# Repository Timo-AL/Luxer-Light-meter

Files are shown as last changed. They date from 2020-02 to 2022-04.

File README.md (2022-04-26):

# Lux-Light-meter
A light meter designed for taking photo（用于摄影的测光表）

## 如何制作

LMG2MB_gerber文件夹里面的zip去找板厂下单，建议嘉立创哑光黑阻焊，减少反光影响

LMG2MV_BOM.xlsx 对照采购原件，尤其注意type-c封装

R11限流电阻根据情况使用，我用的VA 3.3V的1602，选的0欧

安装luattool v2，下载库中的LuatOS-SoC_V0007_AIR103.soc和main.lua

调节旋钮，使液晶屏字符清晰，最好用陶瓷螺丝刀，小心短路

## 如何使用
avatar

B1 电源开关

B2 模式选择，长按在A（光圈优先），S（快门优先），L（低感光度光圈优先），I（感光度设置）模式之间切换

R1 曝光补偿旋钮

R2 参数旋钮

D1 电池电压，低于3.4时需要充电

D2 曝光误差，误差大于0.3EV时显示+，小于-0.3EV显示减号，大于±1EV显示E，小于±0.3EV显示=

D3 ISO值

D4 工作模式

D4 快门速度，速度低于1S会以“秒数"”格式显示

D6 光圈

D7 曝光补偿，设置感光度时该位置显示低感值

## 下载固件

avatar

按如图所示线序与CH340串口模块连接，TX和RX需要交叉，不连接VCC

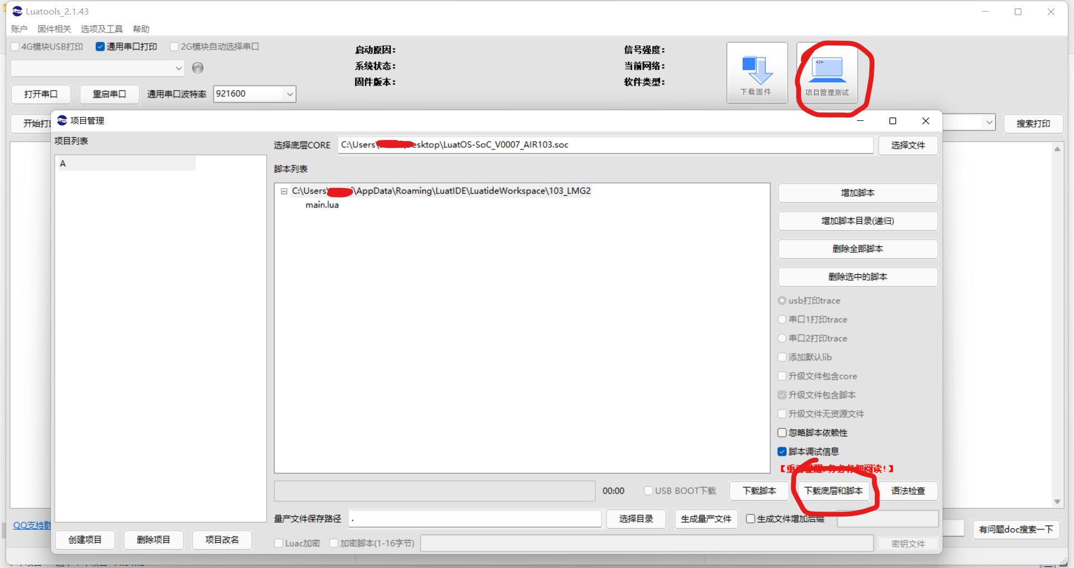
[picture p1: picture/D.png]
avatar


按如图所示方法下载固件，开始下载后打开打开测光表电源

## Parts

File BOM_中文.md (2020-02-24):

名称|丝印|数量|备注
-|-|-|-
外壳|无|1|3D打印仓库中的STEP文件
PCB|无|1|制造文件可以在仓库中下载
旋转编码器|JP5|1|Nidec SD-1110 外壳10*10 手柄直径3.9
DC插座|DC1|1|面板安装，开孔直径8
船型开关|JP3|1|面板安装，开孔6.8*19.2
按键开关|JP5|1|面板安装，开孔直径7.5，无自锁
FPC连接器|FCP1~FCP2|2|16P间隔1.0mm
FPC线|N.A.|1|适合连接器即可
Arduino Nano|MODUL1|1|无
电源管理模块|MODUL2|1|MH-CD42
HPDL1414|D1~D4|1|no remark
传感器|JP2|1|B-LUX-V30B

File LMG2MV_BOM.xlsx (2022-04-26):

Date: | 2022-04-26 18:18
Tool: | Eeschema (6.99.0-1665-g4ee6cfe5b6)
Generator: | C:\Program Files\KiCad\6.99\bin\scripting\plugins/bom_csv_grouped_by_value_with_fp.py
Component Count: | 56
Ref | Qnty | Value | Footprint | Description | Vendor
C1, C2, C3, C4, C6, C7, C8, C9, C10, C16, C25, | 11 | 100nf | Capacitor_SMD:C_0603_1608Metric
C12, C14, C22, | 3 | 10uf | Capacitor_SMD:C_0603_1608Metric
C13, | 1 | 100nF | Capacitor_SMD:C_0603_1608Metric
C15, C17, | 2 | 10uf | Capacitor_SMD:CP_Elec_4x4.5
C18, C19, C20, C21, | 4 | 20pf | Capacitor_SMD:C_0603_1608Metric
C23, C24, | 2 | 100uf | Capacitor_SMD:CP_Elec_6.3x5.4
D1, D2, | 2 | LED | LED_SMD:LED_0805_2012Metric
J1, | 1 | USB_C_Receptacle_USB2.0 | Connector_USB:USB_C_Receptacle_XKB_U262-16XN-4BVC11
J3, | 1 | Conn_01x04 | Connector_PinHeader_2.54mm:PinHeader_1x04_P2.54mm_Vertical
R1, R2, | 2 | 5.1K | Resistor_SMD:R_0603_1608Metric
R3, | 1 | 1.2K | Resistor_SMD:R_0603_1608Metric
R4, R5, | 2 | 200 | Resistor_SMD:R_0603_1608Metric
R6, R7, | 2 | 10k | Resistor_SMD:R_0603_1608Metric
R8, | 1 | 1k | Resistor_SMD:R_0603_1608Metric
R9, R10, | 1 | 4.22k | Resistor_SMD:R_0603_1608Metric | 精度千分之一
R11, | 1 | 510 | Resistor_SMD:R_0603_1608Metric
RV1, | 1 | 10k | Potentiometer_THT:Potentiometer_Vishay_T73XW_Horizontal | 调整对比度的时候手一定要稳，惨痛教训
SW1, SW2, | 2 | XKB7070-Z | FP:SW-TH_6P-L7.0-W7.0-P2.00
U1, | 1 | TP4056 | Package_SO:SOIC-8-1EP_3.9x4.9mm_P1.27mm_EP2.29x3mm
U2, | 1 | ME6211C33 | Package_TO_SOT_SMD:SOT-23-5
U3, | 1 | BH1620FVC-TR | FP:WSOF-5_L1.6-W1.2-P0.50-TL
U4, | 1 | BH1620FVC-TR | FP:PinHeader_1x05_P1.27mm_Vertical_SMD_Pin1Right
U5, | 1 | AIR103_CORE_QFN | FP:QFN-56_L6.0-W6.0-P0.35-BL-EP4.7
U6, U7, | 2 | BCD8421_3-3 | FP:BCD8421_3-3
U8, | 1 | RC1602A | Display:WC1602A | 推荐使用VA屏，对比度高
U9, | 1 | LMC6482 | Package_SO:SOIC-8_3.9x4.9mm_P1.27mm
Y1, | 1 | 40MHz | Crystal:Crystal_SMD_TXC_7A-2Pin_5x3.2mm
J2 | 1 | 803040电池
 | 1 | 余弦修正器 |  | 就是光照传感器的盖子，外径25mm左右

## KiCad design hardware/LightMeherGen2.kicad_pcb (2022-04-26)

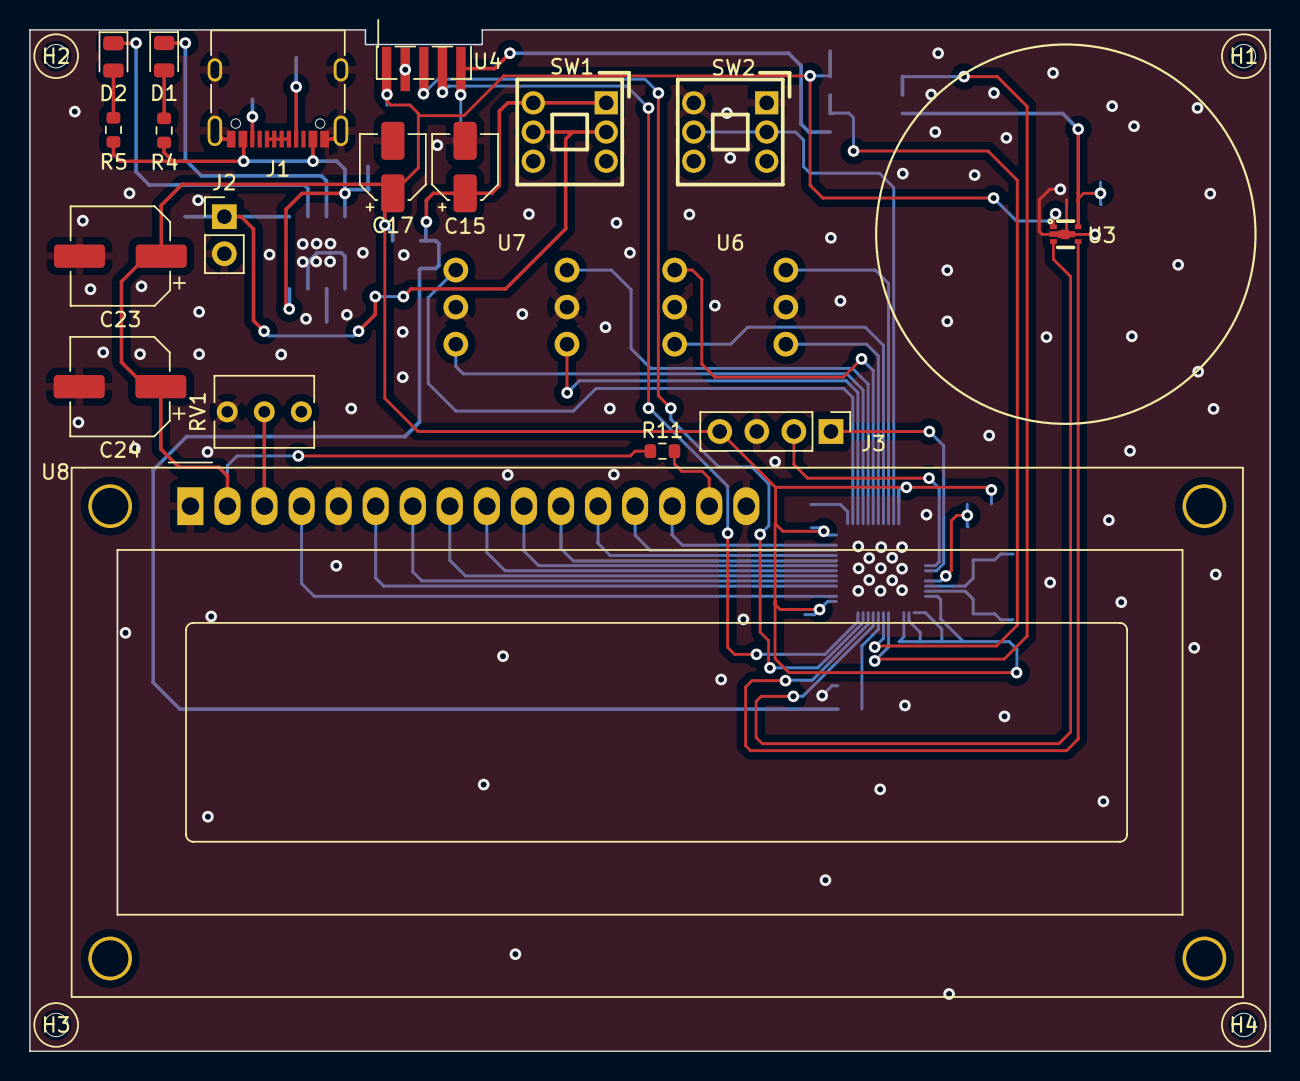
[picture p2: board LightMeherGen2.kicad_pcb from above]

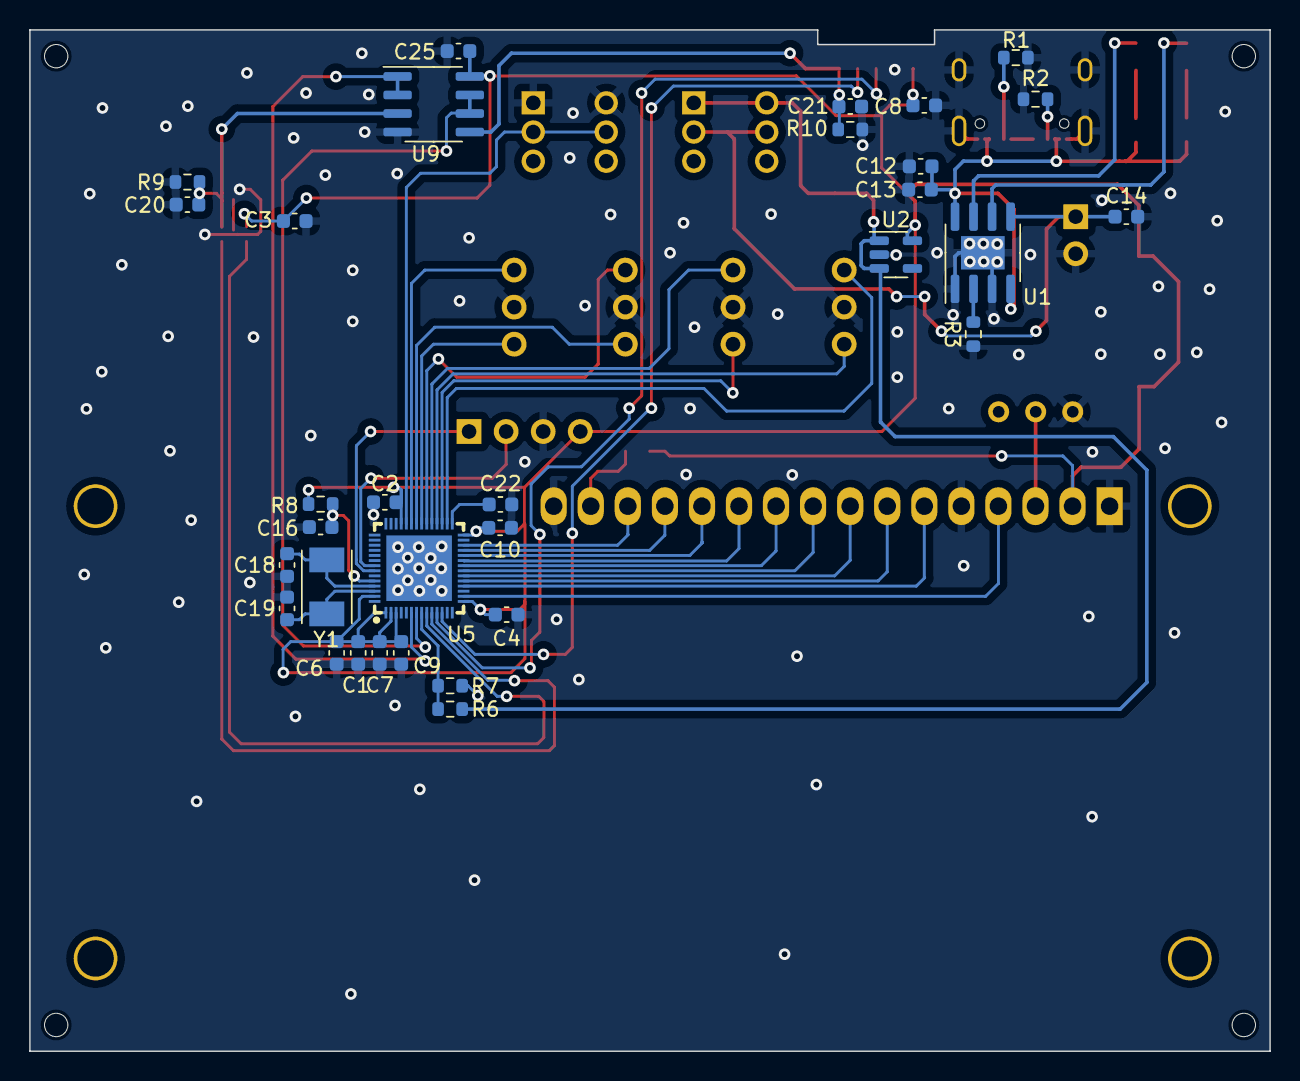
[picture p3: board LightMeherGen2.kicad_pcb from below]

Board: 2 copper layers, 85.0 x 70.0 mm, 56 parts (32 on the bottom side), 49 nets.

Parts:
C1, C2, C3, C4, C6, C7, C8, C9, C10, C16, C25: 100nf; C_0603_1608Metric
C12, C14, C22: 10uf; C_0603_1608Metric
C13: 100nF; C_0603_1608Metric
C15, C17: 10uf; CP_Elec_4x4.5
C18, C19, C20, C21: 20pf; C_0603_1608Metric
C23, C24: 100uf; CP_Elec_6.3x5.4
D1, D2: LED; LED_0805_2012Metric
H1, H2, H3, H4: MountingHole; MH_M1.5
J1: USB_C_Receptacle_USB2.0; USB_C_Receptacle_XKB_U262-16XN-4BVC11
J2: Conn_01x02; PinHeader_1x02_P2.54mm_Vertical
J3: Conn_01x04; PinHeader_1x04_P2.54mm_Vertical
R1, R2: 5.1K; R_0603_1608Metric
R3: 1.2K; R_0603_1608Metric
R4, R5: 200; R_0603_1608Metric
R6, R7: 10k; R_0603_1608Metric
R8: 1k; R_0603_1608Metric
R9: 4.22k; R_0603_1608Metric
R10: 4.22K; R_0603_1608Metric
R11: 510; R_0603_1608Metric
RV1: 10k; Potentiometer_Vishay_T73XW_Horizontal
SW1, SW2: XKB7070-Z; SW-TH_6P-L7.0-W7.0-P2.00
U1: TP4056; SOIC-8-1EP_3.9x4.9mm_P1.27mm_EP2.29x3mm
U2: LN1134-3.3; SOT-23-5
U3: BH1620FVC-TR; WSOF-5_L1.6-W1.2-P0.50-TL
U4: BH1620FVC-TR; PinHeader_1x05_P1.27mm_Vertical_SMD_Pin1Right
U5: AIR103_CORE_QFN; QFN-56_L6.0-W6.0-P0.35-BL-EP4.7
U6, U7: BCD8421_3-3
U8: RC1602A; WC1602A
U9: LMC6482; SOIC-8_3.9x4.9mm_P1.27mm
Y1: 40MHz; Crystal_SMD_TXC_7A-2Pin_5x3.2mm

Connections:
+5V: C12.2, C13.2, J1.A4 (VBUS), J1.A9 (VBUS), J1.B4 (VBUS), J1.B9 (VBUS), R4.2, R5.2, U1.4 (VCC), U1.8 (CE)
/RX: J3.2, U5.07 (U0_RX)
/TX: J3.1, U5.08 (U0_TX)
GND: C1.2, C2.2, C3.2, C4.2, C6.2, C7.2, C8.2, C9.2, C10.2, C12.1, C13.1, C14.2, C15.2, C16.2, C17.2, C18.2, C19.2, C20.2, C21.2, C22.2, C23.2, C24.2, C25.2, J1.A1 (GND), J1.A12 (GND), J1.B1 (GND), J1.B12 (GND), J1.S1 (SHIELD), J2.2, J3.3, R1.1, R2.1, R3.1, R7.2, R9.2, R10.2, RV1.1, SW2.1, SW2.4, U1.1 (TEMP), U1.3 (GND), U1.9 (EXPAD), U2.2 (GND), U3.2 (GND), U4.2 (GND), U5.57 (EXPDA), U6.2 (C), U6.5 (C), U7.2 (C), U7.5 (C), U8.1 (VSS), U8.5 (R/W), U8.16 (K), U9.4 (V-)
unnamed: D1.2 (A), R4.1
unnamed: D1.1 (K), U1.7 (CHRG)
unnamed: D2.2 (A), R5.1
unnamed: D2.1 (K), U1.6 (STDBY)
unnamed: J1.A5 (CC1), R1.2
unnamed: J1.B5 (CC2), R2.2
unnamed: J1.A6 (D+), J1.A7 (D-), J1.B6 (D+), J1.B7 (D-)
unnamed: C14.1, J2.1, SW1.2, SW1.5, U1.5 (BATT)
unnamed: R3.2, U1.2 (PROG)
unnamed: C15.1, R6.1, SW1.1, SW1.4, U2.1 (VIN), U2.3 (ON/~OFF)
unnamed: U3.3 (GC1), U5.23 (PA_05)
unnamed: U3.4 (GC2), U5.24 (PA_06)
unnamed: C20.1, R9.1, U3.5 (IOUT), U9.3 (+)
unnamed: U4.3 (GC1), U5.25 (PA_07)
unnamed: U4.4 (GC2), U5.26 (PA_08)
unnamed: C21.1, R10.1, U4.5 (IOUT), U9.5 (+)
unnamed: C22.1, U5.43 (CAP)
unnamed: U5.20 (PA_02), U9.1, U9.2 (-)
unnamed: U5.21 (PA_03), U9.6 (-), U9.7
unnamed: R6.2, R7.1, U5.22 (PA_04)
unnamed: U5.30 (PA_11), U8.4 (RS)
unnamed: U5.32 (PA_13), U8.6 (E)
unnamed: U5.33 (PA_14), U8.7 (DB0)
unnamed: U5.34 (PA_15), U8.8 (DB1)
unnamed: U5.35 (PB_00), U8.9 (DB2)
unnamed: U5.36 (PB_01), U8.10 (DB3)
unnamed: U5.37 (PB_02), U8.11 (DB4)
unnamed: U5.38 (PB_03), U8.12 (DB5)
unnamed: U5.40 (PB_04), U8.14 (DB7)
unnamed: U5.44 (PB_06), U7.1
unnamed: U5.45 (PB_07), U7.4 (2)
unnamed: U5.46 (PB_08), U7.3 (4)
unnamed: U5.47 (PB_09), U7.6 (8)
unnamed: SW2.2, SW2.5, U5.52 (PB_10)
unnamed: U5.48 (PB_12), U6.1
unnamed: U5.49 (PB_13), U6.4 (2)
unnamed: U5.50 (PB_14), U6.3 (4)
unnamed: U5.51 (PB_15), U6.6 (8)
unnamed: U5.39 (PB_27), U8.13 (DB6)
unnamed: C16.1, R8.2, U5.10 (RESTET)
unnamed: C19.1, U5.12 (XTAL_IN), Y1.1
unnamed: C18.1, U5.11 (XTAL_OUT), Y1.2
unnamed: R11.2, U8.15 (A/VEE)
unnamed: RV1.2, U8.3 (VO)
VCC: C1.1, C2.1, C3.1, C4.1, C6.1, C7.1, C8.1, C9.1, C10.1, C17.1, C23.1, C24.1, C25.1, J3.4, R8.1, R11.1, U2.5 (VOUT), U3.1 (VCC), U4.1 (VCC), U5.13 (VDD33), U5.15 (VDD33), U5.16 (VDD33), U5.17 (VDD33), U5.29 (VDD33), U5.42 (VDD33), U5.53 (VDD33), U8.2 (VDD), U9.8 (V+)

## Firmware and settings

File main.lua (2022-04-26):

-- LuaTools需要PROJECT和VERSION这两个信息
PROJECT = 'helloworld'
VERSION = '1.0.0'

-- 引入必要的库文件(lua编写), 内部库不需要require
local sys = require 'sys'
log.info('main', 'hello world')

print(_VERSION)

--定义所有IO
DISP_array = {11, 13, 14, 15, 16, 17, 18, 19, 43, 20}
--屏幕R/S,ENABLE,DB0-DB7
AEncoder1 = {23, 22, 25, 24}
--BCD编码器1,2,4,8
AEncoder2 = {29, 28, 31, 30}
--BCD编码器1,2,4,8
CG11 = gpio.setup(5, 0, gpio.PULLUP)
CG12 = gpio.setup(6, 0, gpio.PULLUP)
adc.open(3)
LSensor1 = {CG11, CG12, 3}
--传感器CG1,CG2,Analog
adc.open(1)
--电池电压
KEY = gpio.setup(26, nil, gpio.PULLUP)

--测光数据查找表
MOD_table_1 = {1, "A"}
MOD_table_2 = {2, "S"}
MOD_table_3 = {3, "L"}
MOD_table_4 = {4, "I"}
MOD_table = {MOD_table_1, MOD_table_2, MOD_table_3, MOD_table_4}
MOD_table_1 = nil
MOD_table_2 = nil
MOD_table_3 = nil
MOD_table_4 = nil
--模式表

ISO_table_1 = {1,   2.0, " ", " ", "2", "5"}
ISO_table_2 = {2,   1.0, " ", " ", "5", "0"}
ISO_table_3 = {3,   0.5, " ", " ", "7", "5"}
ISO_table_4 = {4,   0.0, " ", "1", "0", "0"}
ISO_table_5 = {5,  -0.5, " ", "1", "5", "0"}
ISO_table_6 = {6,  -1.0, " ", "2", "0", "0"}
ISO_table_7 = {7,  -1.3, " ", "2", "5", "0"}
ISO_table_8 = {8,  -1.6, " ", "3", "2", "0"}
ISO_table_9 = {9,  -2.0, " ", "4", "0", "0"}
ISO_table_10= {10, -2.3, " ", "5", "0", "0"}
ISO_table_11= {11, -2.6, " ", "6", "4", "0"}
ISO_table_12= {12, -3.0, " ", "8", "0", "0"}
ISO_table_13= {13, -3.5, "1", "2", "0", "0"}
ISO_table_14= {14, -4.0, "1", "6", "0", "0"}
ISO_table_15= {15, -5.0, "3", "2", "0", "0"}
ISO_table_16= {16, -6.0, "6", "4", "0", "0"}
ISO_table = {ISO_table_1, ISO_table_2, ISO_table_3, ISO_table_4, ISO_table_5, ISO_table_6, ISO_table_7, ISO_table_8, ISO_table_9, ISO_table_10, ISO_table_11, ISO_table_12, ISO_table_13, ISO_table_14, ISO_table_15, ISO_table_16}
ISO_table_1 = nil
ISO_table_2 = nil
ISO_table_3 = nil
ISO_table_4 = nil
ISO_table_5 = nil
ISO_table_6 = nil
ISO_table_7 = nil
ISO_table_8 = nil
ISO_table_9 = nil
ISO_table_10= nil
ISO_table_11= nil
ISO_table_12= nil
ISO_table_13= nil
ISO_table_14= nil
ISO_table_15= nil
ISO_table_16= nil
--感光度表

APE_table_1 = {1,   0.0, "1", ".", "0"}
APE_table_2 = {2,   0.5, "1", ".", "2"}
APE_table_3 = {3,   1.0, "1", ".", "4"}
APE_table_4 = {4,   1.6, "1", ".", "8"}
APE_table_5 = {5,   2.0, "2", ".", "0"}
APE_table_6 = {6,   3.0, "2", ".", "8"}
APE_table_7 = {7,   3.6, "3", ".", "6"}
APE_table_8 = {8,   4.0, "4", ".", "0"}
APE_table_9 = {9,   5.0, "5", ".", "6"}
APE_table_10= {10,  6.0, "8", " ", " "}
APE_table_11= {11,  7.0, "1", "1", " "}
APE_table_12= {12,  8.0, "1", "6", " "}
APE_table_13= {13,  9.0, "2", "2", " "}
APE_table_14= {14, 10.0, "3", "2", " "}
APE_table_15= {15, 11.0, "4", "5", " "}
APE_table_16= {16, 12.0, "6", "4", " "}
APE_table = {APE_table_1, APE_table_2, APE_table_3, APE_table_4, APE_table_5, APE_table_6, APE_table_7, APE_table_8, APE_table_9, APE_table_10, APE_table_11, APE_table_12, APE_table_13, APE_table_14, APE_table_15, APE_table_16}
APE_table_1 = nil
APE_table_2 = nil
APE_table_3 = nil
APE_table_4 = nil
APE_table_5 = nil
APE_table_6 = nil
APE_table_7 = nil
APE_table_8 = nil
APE_table_9 = nil
APE_table_10= nil
APE_table_11= nil
APE_table_12= nil
APE_table_13= nil
APE_table_14= nil
APE_table_15= nil
APE_table_16= nil
--光圈表

SHT_table_1 = {1,  -3.0, " ", " ", "8", "\""}
SHT_table_2 = {2,  -2.0, " ", " ", "4", "\""}
SHT_table_3 = {3,  -1.0, " ", " ", "2", "\""}
SHT_table_4 = {4,   0.0, " ", " ", "1", "\""}
SHT_table_5 = {5,   1.0, " ", " ", " ", "2"}
SHT_table_6 = {6,   2.0, " ", " ", " ", "4"}
SHT_table_7 = {7,   3.0, " ", " ", " ", "8"}
SHT_table_8 = {8,   4.0, " ", " ", "1", "5"}
SHT_table_9 = {9,   5.0, " ", " ", "3", "0"}
SHT_table_10= {10,  6.0, " ", " ", "6", "0"}
SHT_table_11= {11,  7.0, " ", "1", "2", "5"}
SHT_table_12= {12,  8.0, " ", "2", "5", "0"}
SHT_table_13= {13,  9.0, " ", "5", "0", "0"}
SHT_table_14= {14, 10.0, "1", "0", "0", "0"}
SHT_table_15= {15, 11.0, "2", "0", "0", "0"}
SHT_table_16= {16, 12.0, "4", "0", "0", "0"}
SHT_table = {SHT_table_1, SHT_table_2, SHT_table_3, SHT_table_4, SHT_table_5, SHT_table_6, SHT_table_7, SHT_table_8, SHT_table_9, SHT_table_10, SHT_table_11, SHT_table_12, SHT_table_13, SHT_table_14, SHT_table_15, SHT_table_16}
SHT_table_1 = nil
SHT_table_2 = nil
SHT_table_3 = nil
SHT_table_4 = nil
SHT_table_5 = nil
SHT_table_6 = nil
SHT_table_7 = nil
SHT_table_8 = nil
SHT_table_9 = nil
SHT_table_10= nil
SHT_table_11= nil
SHT_table_12= nil
SHT_table_13= nil
SHT_table_14= nil
SHT_table_15= nil
SHT_table_16= nil
--快门表

COM_table_1 = {1,  -2.3, "-", "2", ".", "3"}
COM_table_2 = {2,  -2.0, "-", "2", ".", "0"}
COM_table_3 = {3,  -1.6, "-", "1", ".", "6"}
COM_table_4 = {4,  -1.3, "-", "1", ".", "3"}
COM_table_5 = {5,  -1.0, "-", "1", ".", "0"}
COM_table_6 = {6,  -0.6, "-", "0", ".", "6"}
COM_table_7 = {7,  -0.3, "-", "0", ".", "3"}
COM_table_8 = {8,   0.0, " ", "0", ".", "0"}
COM_table_9 = {9,   0.3, "+", "0", ".", "3"}
COM_table_10= {10,  0.6, "+", "0", ".", "6"}
COM_table_11= {11,  1.0, "+", "1", ".", "0"}
COM_table_12= {12,  1.3, "+", "1", ".", "3"}
COM_table_13= {13,  1.6, "+", "1", ".", "6"}
COM_table_14= {14,  2.0, "+", "2", ".", "0"}
COM_table_15= {15,  2.3, "+", "2", ".", "3"}
COM_table_16= {16,  2.6, "+", "2", ".", "6"}
COM_table = {COM_table_1, COM_table_2, COM_table_3, COM_table_4, COM_table_5, COM_table_6, COM_table_7, COM_table_8, COM_table_9, COM_table_10, COM_table_11, COM_table_12, COM_table_13, COM_table_14, COM_table_15, COM_table_16}
COM_table_1 = nil
COM_table_2 = nil
COM_table_3 = nil
COM_table_4 = nil
COM_table_5 = nil
COM_table_6 = nil
COM_table_7 = nil
COM_table_8 = nil
COM_table_9 = nil
COM_table_10= nil
COM_table_11= nil
COM_table_12= nil
COM_table_13= nil
COM_table_14= nil
COM_table_15= nil
COM_table_16= nil
--补偿表

LOW_table_1 = {1,   2.3, " ", " ", "2", "1"}
LOW_table_2 = {2,   2.6, " ", " ", "1", "6"}
LOW_table_3 = {3,   3.0, " ", " ", "1", "2"}
LOW_table_4 = {4,   3.3, " ", " ", "1", "0"}
LOW_table_5 = {5,   3.6, " ", " ", " ", "8"}
LOW_table_6 = {6,   4.0, " ", " ", " ", "6"}
LOW_table_7 = {7,   4.3, " ", " ", " ", "5"}
LOW_table_8 = {8,   4.6, " ", " ", " ", "4"}
LOW_table_9 = {9,   5.0, " ", " ", " ", "3"}
LOW_table_10= {10,  5.3, " ", "2", ".", "5"}
LOW_table_11= {11,  5.6, " ", " ", " ", "2"}
LOW_table_12= {12,  6.0, " ", "1", ".", "5"}
LOW_table_13= {13,  6.3, "1", ".", "2", "5"}
LOW_table_14= {14,  6.6, " ", " ", " ", "1"}
LOW_table_15= {15,  7.0, "0", ".", "7", "5"}
LOW_table_16= {16,  8.0, ".", "3", "7", "5"}
LOW_table = {LOW_table_1, LOW_table_2, LOW_table_3, LOW_table_4, LOW_table_5, LOW_table_6, LOW_table_7, LOW_table_8, LOW_table_9, LOW_table_10, LOW_table_11, LOW_table_12, LOW_table_13, LOW_table_14, LOW_table_15, LOW_table_16}
LOW_table_1 = nil
LOW_table_2 = nil
LOW_table_3 = nil
LOW_table_4 = nil
LOW_table_5 = nil
LOW_table_6 = nil
LOW_table_7 = nil
LOW_table_8 = nil
LOW_table_9 = nil
LOW_table_10= nil
LOW_table_11= nil
LOW_table_12= nil
LOW_table_13= nil
LOW_table_14= nil
LOW_table_15= nil
LOW_table_16= nil
--慢门表

SOW_table_1 = {1,   6.0, " ", " ", "6", "0"}
SOW_table_2 = {2,   5.0, " ", " ", "3", "0"}
SOW_table_3 = {3,   4.0, " ", " ", "1", "5"}
SOW_table_4 = {4,   3.0, " ", " ", " ", "8"}
SOW_table_5 = {5,   2.0, " ", " ", " ", "4"}
SOW_table_6 = {6,   1.0, " ", " ", " ", "2"}
SOW_table_7 = {7,   0.0, " ", " ", "1", "\""}
SOW_table_8 = {8,  -1.0, " ", " ", "2", "\""}
SOW_table_9 = {9,  -2.0, " ", " ", "4", "\""}
SOW_table_10= {10, -3.0, " ", " ", "8", "\""}
SOW_table_11= {11, -4.0, " ", "1", "5", "\""}
SOW_table_12= {12, -5.0, " ", "3", "0", "\""}
SOW_table_13= {13, -6.0, " ", " ", "1", "'"}
SOW_table_14= {14, -7.0, " ", " ", "2", "'"}
SOW_table_15= {15, -8.0, " ", " ", "4", "'"}
SOW_table_16= {16, -9.0, " ", " ", "8", "'"}
SOW_table = {SOW_table_1, SOW_table_2, SOW_table_3, SOW_table_4, SOW_table_5, SOW_table_6, SOW_table_7, SOW_table_8, SOW_table_9, SOW_table_10, SOW_table_11, SOW_table_12, SOW_table_13, SOW_table_14, SOW_table_15, SOW_table_16}
SOW_table_1 = nil
SOW_table_2 = nil
SOW_table_3 = nil
SOW_table_4 = nil
SOW_table_5 = nil
SOW_table_6 = nil
SOW_table_7 = nil
SOW_table_8 = nil
SOW_table_9 = nil
SOW_table_10= nil
SOW_table_11= nil
SOW_table_12= nil
SOW_table_13= nil
SOW_table_14= nil
SOW_table_15= nil
SOW_table_16= nil
--慢门表

function DISP_IOinit(DISPIO) 
--初始化IO接口，传出
    DISP_IO = {}
    for i,v in ipairs(DISPIO) do
    --    print(DISPIO[i])
        DISP_IO[i] = gpio.setup(DISPIO[i], 0, gpio.PULLUP)
    end
    DISP_IO[2](0)
    timer.mdelay(1)
    return DISP_IO
end

function DISP_WriteRaw(IO, RS, DATA)
--写入原始数据，IO为IOinit返回值，RS为指令/数据切换
    if (DATA >255)
    then
        DATA = DATA % 255
        print("write err,data too bing")
    end
    --print(DATA)
--取余，限制数据大小
    DIV = 128
    DATA_bi = {}
    for i=1, 8, 1 do
        if(DATA >= DIV)
        then
            DATA_bi[i] = 1
            DATA = DATA - DIV
        else
            DATA_bi[i] = 0
        end
        DIV = DIV/2
        --print(DATA_bi[i])
    end
--转二进制
    if(RS ~= 0)
    then
        DISP_IO[1](1)
    --    print("数据")
    else
        DISP_IO[1](0)
    --    print("指令")
    end
--指令数据模式转换
    DISP_IO[3](DATA_bi[8])
    DISP_IO[4](DATA_bi[7])
    DISP_IO[5](DATA_bi[6])
    DISP_IO[6](DATA_bi[5])
    DISP_IO[7](DATA_bi[4])
    DISP_IO[8](DATA_bi[3])
    DISP_IO[9](DATA_bi[2])
    DISP_IO[10](DATA_bi[1])
    timer.mdelay(5)
    DISP_IO[2](1)
    --print("EN_UP")
    timer.mdelay(1)
    DISP_IO[2](0)
--写数据
end

function DISP_SCREENinit(IOINIT)
--传入初始化结果，初始化屏幕
DISP_WriteRaw(IOINIT, 0, 56) --数据位为8位，显示两行，5x7字符
timer.mdelay(5)
DISP_WriteRaw(IOINIT, 0, 12) --开启显示，不显示光标
timer.mdelay(5)
DISP_WriteRaw(IOINIT, 0, 6) --自动移动光标，不移动屏幕
timer.mdelay(5)
DISP_WriteRaw(IOINIT, 0, 1) --清屏
timer.mdelay(5)
DISP_WriteRaw(IOINIT, 0, 2) --光标归位
timer.mdelay(5)
end

function DISP_ShowChar(IO, RPOS, CPOS, CHAR)
--在指定位置显示指定字符，IO为初始化数组，RPOS为行，CPOS为列，均以零开始，CHAR为显示字符
    DD = 0x80
    if(RPOS == 1)
    then
        DD = DD + 0x40
    end
    DD = DD + CPOS
    DISP_WriteRaw(IO, 0, DD)
--移动光标
    CC = string.byte(CHAR)
    --print(CC)
    DISP_WriteRaw(IO, 1, CC)
--显示内容
    DISP_WriteRaw(IO, 0, 0x80 + 0x1F)
--移出光标
end

function AEncoder_scan(AEIO)
--读取BCD8421编码器数值，传出
    RAEncoder = 0
    E1 = gpio.setup(AEIO[1], nil, gpio.PULLUP)
    E2 = gpio.setup(AEIO[2], nil, gpio.PULLUP)
    E3 = gpio.setup(AEIO[3], nil, gpio.PULLUP)
    E4 = gpio.setup(AEIO[4], nil, gpio.PULLUP)
    RAEncoder1 = E1()
    RAEncoder2 = E2()
    RAEncoder3 = E3()
    RAEncoder4 = E4()
--上拉读取数据
    if (RAEncoder1 == 0 )
    then
        RAEncoder = RAEncoder + 1
    end
    if (RAEncoder2 == 0 )
    then
        RAEncoder = RAEncoder + 2
    end
    if (RAEncoder3 == 0 )
    then
        RAEncoder = RAEncoder + 4
    end
    if (RAEncoder4 == 0 )
    then
        RAEncoder = RAEncoder + 8
    end
--BCD码累加
    gpio.close(AEIO[1])
    gpio.close(AEIO[2])
    gpio.close(AEIO[3])
    gpio.close(AEIO[4])
--IO口恢复高阻态
    return RAEncoder
end

function LightSenser_read(LIO)
--传入传感器IO，返回以Lux为单位的照度
    LIO[1](0)
    LIO[2](1)
    alpha = 0.057
    timer.mdelay(1)
    LR, LV = adc.read(LIO[3])
    if (LV <100)
    then
        LIO[1](1)
        LIO[2](0)
        timer.mdelay(1)
        LR, LV = adc.read(LIO[3])
        alpha = 0.57
    end
    if (LV >2000)
    then
        LIO[1](1)
        timer.mdelay(1)
        LR, LV = adc.read(LIO[3])
        alpha = 0.0057
    end
    lux = (LV/1000)/(alpha*0.00422)
    return lux
end

--调用开始

SK = 2.5
--传感器校正参数
LK = 1.2
--线性校正参数
MOD = 1
--模式计数
ISO = 4
--ISO计数
COM = AEncoder_scan(AEncoder1)
--曝光补偿
PAR = AEncoder_scan(AEncoder2)
--参数选择

D1602 = DISP_IOinit(DISP_array)
DISP_SCREENinit(D1602)
DISP_ShowChar(D1602, 0, 0, "B")
DISP_ShowChar(D1602, 0, 1, "A")
DISP_ShowChar(D1602, 0, 2, "T")
DISP_ShowChar(D1602, 0, 4, ".")
DISP_ShowChar(D1602, 0, 9, "I")
DISP_ShowChar(D1602, 0, 10, "S")
DISP_ShowChar(D1602, 0, 11, "O")
DISP_ShowChar(D1602, 1, 7, "F")
--初始化屏幕

EV_ISO = ISO_table[ISO][2]
DISP_ShowChar(D1602, 0, 12, ISO_table[ISO][3])
DISP_ShowChar(D1602, 0, 13, ISO_table[ISO][4])
DISP_ShowChar(D1602, 0, 14, ISO_table[ISO][5])
DISP_ShowChar(D1602, 0, 15, ISO_table[ISO][6])
--ISO调用默认值（100）

while 1 do

    AE1 = AEncoder_scan(AEncoder1) + 1
    AE2 = AEncoder_scan(AEncoder2) + 1
    --读取编码器位置
    SWRead = KEY()
    if (SWRead == 0 and SWReadBF ~= SWRead)
    then
        timer.mdelay(5)
        SWRead = KEY()
        if (SWRead == 0)
        then
            MOD = MOD + 1
        end
        if (MOD >4)
        then
            MOD = 1
        end
        if(MOD == 3)
        then
            LOW_ISO = LOW_table[ISO][2]
            DISP_ShowChar(D1602, 0, 12, LOW_table[ISO][3])
            DISP_ShowChar(D1602, 0, 13, LOW_table[ISO][4])
            DISP_ShowChar(D1602, 0, 14, LOW_table[ISO][5])
            DISP_ShowChar(D1602, 0, 15, LOW_table[ISO][6])
        end
        if(MOD <3)
        then
            EV_ISO = ISO_table[ISO][2]
            DISP_ShowChar(D1602, 0, 12, ISO_table[ISO][3])
            DISP_ShowChar(D1602, 0, 13, ISO_table[ISO][4])
            DISP_ShowChar(D1602, 0, 14, ISO_table[ISO][5])
            DISP_ShowChar(D1602, 0, 15, ISO_table[ISO][6])
        end
    end
    SWReadBF = SWRead
    --检查按钮，切换模式

    print("lux")
    LUXBK = 0
    for i=1, 10, 1 do
        LUXBK = LUXBK + (LightSenser_read(LSensor1)/10)
        timer.mdelay(1)
    end
    LUXAK = LUXBK/SK
    EVT = (math.log(LUXAK) / math.log(2)) + LK
    print("EVT")
    print(EVT)
    --计算曝光度EV

    print("BATT")
    BR, BV = adc.read(1)
    BAT = (BV * 2)/1000
    BAI = tostring(math.floor(BAT))
    BAF = tostring(math.floor((BAT % 1)*10))
    DISP_ShowChar(D1602, 0, 3, BAI)
    DISP_ShowChar(D1602, 0, 5, BAF)
    --显示电池电压

    if (MOD ~=4)
    then
    EV_COM = COM_table[AE1][2]
    DISP_ShowChar(D1602, 1, 12, COM_table[AE1][3])
    DISP_ShowChar(D1602, 1, 13, COM_table[AE1][4])
    DISP_ShowChar(D1602, 1, 14, COM_table[AE1][5])
    DISP_ShowChar(D1602, 1, 15, COM_table[AE1][6])
    end
    --读取曝光补偿

    if (MOD == 1)
    --光圈优先模式
    then
        EV_A_FA = APE_table[AE2][2]
        EV_A_SHT = EVT - (EV_ISO + EV_COM + EV_A_FA)
        print("A MOD SHT EV")
        print(EV_A_SHT)
        --计算快门所需EV值
        SHT_CH = {}
        for i=1, 16, 1 do
            SHT_CH[i] = math.abs(EV_A_SHT - SHT_table[i][2])
        end
        --计算误差
        SHT_USE = 1
        SHT_ABS_ERR = SHT_CH[1]
        for i=2, 16, 1 do
            if(SHT_CH[i] < SHT_ABS_ERR)
            then
                SHT_USE = i
                SHT_ABS_ERR = SHT_CH[i]
            end
        end
        print(SHT_USE)
        SHT_ERR = EV_A_SHT - SHT_table[SHT_USE][2]
        --寻找匹配值
        if (math.abs(SHT_ERR) > 1)
        then
            DISP_ShowChar(D1602, 0, 7, "E")
        end
        if (SHT_ERR >0.3 and SHT_ERR <= 1.0)
        then
            DISP_ShowChar(D1602, 0, 7, "+")
        end
        if (SHT_ERR <-0.3 and SHT_ERR >= -1.0)
        then
            DISP_ShowChar(D1602, 0, 7, "-")
        end
        if (math.abs(SHT_ERR) <=0.3)
        then
            DISP_ShowChar(D1602, 0, 7, "=")
        end
        --误差提示
        DISP_ShowChar(D1602, 1, 0, MOD_table[1][2])
        DISP_ShowChar(D1602, 1, 8, APE_table[AE2][3])
        DISP_ShowChar(D1602, 1, 9, APE_table[AE2][4])
        DISP_ShowChar(D1602, 1,10, APE_table[AE2][5])

        DISP_ShowChar(D1602, 1,2, SHT_table[SHT_USE][3])
        DISP_ShowChar(D1602, 1,3, SHT_table[SHT_USE][4])
        DISP_ShowChar(D1602, 1,4, SHT_table[SHT_USE][5])
        DISP_ShowChar(D1602, 1,5, SHT_table[SHT_USE][6])
    end

    if (MOD == 2)
    --快门优先模式
    then
        EV_S_FS = SHT_table[AE2][2]
        EV_S_APE = EVT - (EV_ISO + EV_COM + EV_S_FS)
        print("S MOD APE EV")
        print(EV_A_SHT)
        --计算光圈所需EV值
        APE_CH = {}
        for i=1, 16, 1 do
            APE_CH[i] = math.abs(EV_S_APE - APE_table[i][2])
        end
        --计算误差
        APE_USE = 1
        APE_ABS_ERR = APE_CH[1]
        for i=2, 16, 1 do
            if(APE_CH[i] < APE_ABS_ERR)
            then
                APE_USE = i
                APE_ABS_ERR = APE_CH[i]
            end
        end
        print(APE_USE)
        APE_ERR = EV_S_APE - APE_table[APE_USE][2]
        --寻找匹配值
        if (math.abs(APE_ERR) > 1)
        then
            DISP_ShowChar(D1602, 0, 7, "E")
        end
        if (APE_ERR >0.3 and APE_ERR <= 1.0)
        then
            DISP_ShowChar(D1602, 0, 7, "+")
        end
        if (APE_ERR <-0.3 and APE_ERR >= -1.0)
        then
            DISP_ShowChar(D1602, 0, 7, "-")
        end
        if (math.abs(APE_ERR) <=0.3)
        then
            DISP_ShowChar(D1602, 0, 7, "=")
        end
        --误差提示
        DISP_ShowChar(D1602, 1, 0, MOD_table[2][2])
        DISP_ShowChar(D1602, 1, 8, APE_table[APE_USE][3])
        DISP_ShowChar(D1602, 1, 9, APE_table[APE_USE][4])
        DISP_ShowChar(D1602, 1,10, APE_table[APE_USE][5])

        DISP_ShowChar(D1602, 1,2, SHT_table[AE2][3])
        DISP_ShowChar(D1602, 1,3, SHT_table[AE2][4])
        DISP_ShowChar(D1602, 1,4, SHT_table[AE2][5])
        DISP_ShowChar(D1602, 1,5, SHT_table[AE2][6])
    end

    if (MOD == 3)
    --低感度模式
    then
        EV_L_FA = APE_table[AE2][2]
        EV_L_SHT = EVT - (LOW_ISO + EV_COM + EV_L_FA)
        print("L MOD SHT EV")
        print(EV_L_SHT)
        --计算快门所需EV值
        L_SHT_CH = {}
        for i=1, 16, 1 do
            L_SHT_CH[i] = math.abs(EV_L_SHT - SOW_table[i][2])
        end
        --计算误差
        L_SHT_USE = 1
        L_SHT_ABS_ERR = L_SHT_CH[1]
        for i=2, 16, 1 do
            if(L_SHT_CH[i] < L_SHT_ABS_ERR)
            then
                L_SHT_USE = i
                L_SHT_ABS_ERR = L_SHT_CH[i]
            end
        end
        print(L_SHT_USE)
        L_SHT_ERR = EV_L_SHT - SOW_table[L_SHT_USE][2]
        --寻找匹配值
        if (math.abs(L_SHT_ERR) > 1)
        then
            DISP_ShowChar(D1602, 0, 7, "E")
        end
        if (L_SHT_ERR >0.3 and L_SHT_ERR <= 1.0)
        then
            DISP_ShowChar(D1602, 0, 7, "+")
        end
        if (L_SHT_ERR <-0.3 and L_SHT_ERR >= -1.0)
        then
            DISP_ShowChar(D1602, 0, 7, "-")
        end
        if (math.abs(L_SHT_ERR) <=0.3)
        then
            DISP_ShowChar(D1602, 0, 7, "=")
        end
        --误差提示
        DISP_ShowChar(D1602, 1, 0, MOD_table[3][2])
        DISP_ShowChar(D1602, 1, 8, APE_table[AE2][3])
        DISP_ShowChar(D1602, 1, 9, APE_table[AE2][4])
        DISP_ShowChar(D1602, 1,10, APE_table[AE2][5])

        DISP_ShowChar(D1602, 1,2, SOW_table[L_SHT_USE][3])
        DISP_ShowChar(D1602, 1,3, SOW_table[L_SHT_USE][4])
        DISP_ShowChar(D1602, 1,4, SOW_table[L_SHT_USE][5])
        DISP_ShowChar(D1602, 1,5, SOW_table[L_SHT_USE][6])
    end

    if (MOD == 4) 
    --设置ISO
    then
        DISP_ShowChar(D1602, 1, 0, MOD_table[4][2])
        ISO = AE2
        DISP_ShowChar(D1602, 0, 12, ISO_table[ISO][3])
        DISP_ShowChar(D1602, 0, 13, ISO_table[ISO][4])
        DISP_ShowChar(D1602, 0, 14, ISO_table[ISO][5])
        DISP_ShowChar(D1602, 0, 15, ISO_table[ISO][6])
        DISP_ShowChar(D1602, 1, 12, LOW_table[ISO][3])
        DISP_ShowChar(D1602, 1, 13, LOW_table[ISO][4])
        DISP_ShowChar(D1602, 1, 14, LOW_table[ISO][5])
        DISP_ShowChar(D1602, 1, 15, LOW_table[ISO][6])
    end

    timer.mdelay(100)
end

-- 用户代码已结束---------------------------------------------
-- 结尾总是这一句
sys.run()
-- sys.run()之后后面不要加任何语句!!!!!

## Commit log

2022-04-26 Delete BOM_物料表 directory
    rm
2022-04-26 Delete PCB directory
    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
2022-04-26 Delete model_模型 directory
    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
    [Luxer_main v10.f3d, Luxer_main v9.step]
2022-04-26 Add files via upload
    new version
    [LightMeherGen2.kicad_pcb, LightMeherGen2.kicad_sch, LightMeherGen2.xlsx]
